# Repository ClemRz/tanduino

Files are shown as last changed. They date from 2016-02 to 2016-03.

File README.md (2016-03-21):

# Tanduino

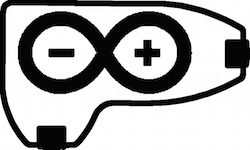
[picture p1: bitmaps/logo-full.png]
Tanduino


Tanduino is an Arduino based project aimed to mimic the analog "tandem" inclinometer + compass.

## User guide

* Power the device with a DC 3.3V to 9V battery.
* Turn on and off the device with the rocking switch.
* Push the temporary button to start the capturing procedure, you will hear a short chirp, hold the device as stable as possible. A second short chirp will be emitted once satisfactory values are read and the laser will go off. If you hear a long chirp push the temporary button again and try to hold the device more steadily.
* Maintain the temporary button pushed during more than 2s to enter in raw mode (for calibration purposes).
* When the laser diode is on don't look at it directly in the eye.
* The backlight level can be adjusted by rotating the 10KΩ trimmer resistor with a screwdriver.
* The laser power can be adjusted by rotating the 10Ω trimmer resistor with a screwdriver.

The compass is tilt compensated by the accelerometer.

The device must be recalibrated each time the hardware design is modified. Particularly if you decide to use a different battery format (4xAA instead of 1x9V for instance).

## Ratings

* Heading precision: ±0.1º
* Pitch precision: ±0.1º
* Power consumption*:
  - hold state: 41mW
  - unhold state: 149mW

*Measured with the lowest backlight level and a regular laser power at 20ºC.

## Developer guide

### Software design

#### Calibration

After any hardware change (PCB, enclosure, battery etc.), the magnetometer needs to be calibrated. This tutorial is a good start:

[Advanced hard and soft iron magnetometer calibration for dummies](http://diydrones.com/profiles/blogs/advanced-hard-and-soft-iron-magnetometer-calibration-for-dummies "Advanced hard and soft iron magnetometer calibration for dummies")

...

#### Dependencies

* [Adafruit Sensor library](https://github.com/adafruit/Adafruit_Sensor "Adafruit Sensor library")
* [Adafruit ADXL345 library](https://github.com/adafruit/Adafruit_ADXL345 "Adafruit ADXL345 library")
* [Adafruit HMC5883 Unified library](https://github.com/adafruit/Adafruit_HMC5883_Unified "Adafruit HMC5883 Unified library")
* [Adafruit GFX library](https://github.com/adafruit/Adafruit-GFX-Library "Adafruit GFX library")
* [Adafruit PCD8544 Nokia 5110 LCD library](https://github.com/adafruit/Adafruit-PCD8544-Nokia-5110-LCD-library "Adafruit PCD8544 Nokia 5110 LCD library")

### Electronic design

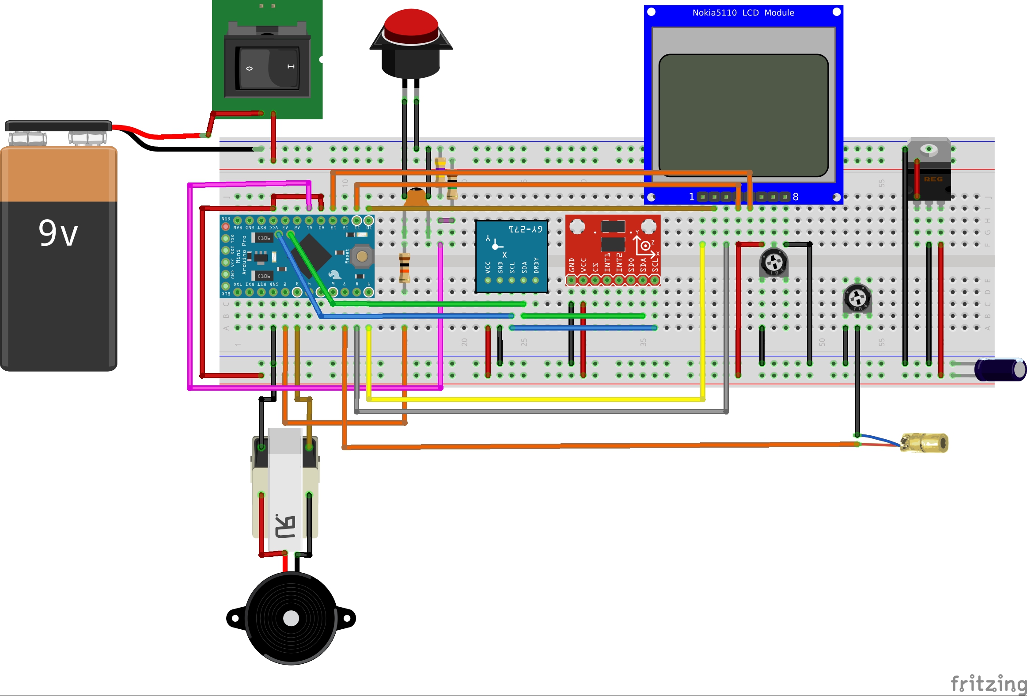
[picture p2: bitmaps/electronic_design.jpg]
Electronic design


#### Hardware list

* Arduino Pro Mini ATmega328 8MHz 3.3V
* Triple Axis Digital Compass HMC5883L
* Triple Axis Accelerometer ADXL345
* 84*48 LCD Display PCD8544
* 5mW 650nm 3V red laser diode
* Rocker on/off button
* Temporary push button
* 10kΩ resistor and 100nF ceramic capacitor for push button debouncing
* 470kΩ and 1MΩ resistors to divide battery voltage sensing
* 10kΩ trimmer resistor to adjust display's backlight
* 10Ω trimmer resistor to adjust laser power
* LT1521 3.3V 300mA voltage regulator and 1µF electrolitic capacitor
* Piezo flat speaker
* Autotransformer (boost piezo voltage)

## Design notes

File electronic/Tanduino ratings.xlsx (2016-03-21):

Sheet: Theorical power ratings
Tanduino operating current rating
Component | Theorical rating (mA)
Voltage regulator LT1521-3.3 | 0.012
Arduino Pro Mini 8MHz 3.3V | 3.58
Laser | 40
ADXL345 | 0.03
HMC5883L | 0.1
PCD8544 (w/t backlight) | 0.2
PCD8544 backlight | 6.8
Battery sensing | 0.006
Total | 50.728

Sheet: Experimental power ratings
Row Labels | Average of Power (mW)
boot | 47.32
hold | 40.51
measuring | 148.54
Grand Total | 122.04

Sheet: Data
running time (ms) | current (mA) | voltage (V) | Power (mW) | State
2619 | 74.7 | 8.46 | 631.96 | boot
2625 | 73.4 | 7.27 | 533.62 | boot
2632 | 11.6 | 7.33 | 85.03 | boot
2638 | 22.9 | 7.88 | 180.45 | boot
2647 | 11.2 | 8.22 | 92.06 | boot
2653 | 40 | 8.06 | 322.40 | boot
2660 | 10.8 | 8.21 | 88.67 | boot
2666 | 49 | 8.14 | 398.86 | boot
2673 | 4 | 8.31 | 33.24 | boot
2679 | 4 | 8.33 | 33.32 | boot
2686 | 6.6 | 8.33 | 54.98 | boot
2693 | 6.7 | 8.27 | 55.41 | boot
2700 | 6.7 | 8.26 | 55.34 | boot
2706 | 6.7 | 8.26 | 55.34 | boot
2713 | 6.9 | 8.26 | 56.99 | boot
2719 | 6.8 | 8.26 | 56.17 | boot
2726 | 6.9 | 8.26 | 56.99 | boot
2733 | 6.9 | 8.26 | 56.99 | boot
2740 | 6.9 | 8.25 | 56.93 | boot
2746 | 7.1 | 8.25 | 58.57 | boot
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

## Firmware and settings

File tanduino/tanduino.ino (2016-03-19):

/**
Copyright (c) 2016, Clément Ronzon
All rights reserved.

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
* Neither the name of tanduino nor the names of its
  contributors may be used to endorse or promote products derived from
  this software without specific prior written permission.

THIS SOFTWARE IS PROVIDED BY THE COPYRIGHT HOLDERS AND CONTRIBUTORS "AS IS"
AND ANY EXPRESS OR IMPLIED WARRANTIES, INCLUDING, BUT NOT LIMITED TO, THE
IMPLIED WARRANTIES OF MERCHANTABILITY AND FITNESS FOR A PARTICULAR PURPOSE ARE
DISCLAIMED. IN NO EVENT SHALL THE COPYRIGHT HOLDER OR CONTRIBUTORS BE LIABLE
FOR ANY DIRECT, INDIRECT, INCIDENTAL, SPECIAL, EXEMPLARY, OR CONSEQUENTIAL
DAMAGES (INCLUDING, BUT NOT LIMITED TO, PROCUREMENT OF SUBSTITUTE GOODS OR
SERVICES; LOSS OF USE, DATA, OR PROFITS; OR BUSINESS INTERRUPTION) HOWEVER
CAUSED AND ON ANY THEORY OF LIABILITY, WHETHER IN CONTRACT, STRICT LIABILITY,
OR TORT (INCLUDING NEGLIGENCE OR OTHERWISE) ARISING IN ANY WAY OUT OF THE USE
OF THIS SOFTWARE, EVEN IF ADVISED OF THE POSSIBILITY OF SUCH DAMAGE.
 */

#include <SPI.h>
#include <Wire.h>
#include <Adafruit_Sensor.h>
#include <Adafruit_ADXL345_U.h>
#include <Adafruit_HMC5883_U.h>
#include <Adafruit_GFX.h>
#include <Adafruit_PCD8544.h>
#include "structures.h"

// Debug options
#define VERBOSE_MODE                  0                       // Echo data to serial port: 0: none, 1 basic info, 2 detailed info, 3 extended info
#define WAIT_TO_START                 0                       // Wait for serial input in setup()

// General
#define MILLISEC                      1000L
#define SEC                           1L
#define MINUTE                        (unsigned int)60L*SEC
#define HOUR                          (unsigned int)60L*MINUTE
#define DAY                           (unsigned long)24L*HOUR

// Error codes
#define ERROR_ADXL345_INIT            1
#define ERROR_HMC5883_INIT            2
const char PROGMEM                                            //Remember to update the buffer when adding a larger string [7]
  errmsg_0[] =                        "",                     //SPARE
  errmsg_1[] =                        "Ac err",               //Accelerometer init error
  errmsg_2[] =                        "Co err";               //Compass init error
const char* const PROGMEM        
  ERROR_MESSAGES[] =                  {errmsg_0, errmsg_1, errmsg_2};

// Pins        
#define REFERENCE_3V3_PIN             A0                      // 3.3V reference for sampling
#define BATTERY_PIN                   A1                      // Battery sensing
#define BUTTON_PIN                    2                       // Interrupt pin
#define PIEZO_PIN                     3                       // Piezo speaker/buzzer pin
#define LASER_PIN                     7                       // Laser pointer
#define PCD8544_DC_PIN                8                       // LCD Data/Command select
#define PCD8544_RST_PIN               9                       // LCD Reset
#define PCD8544_CE_PIN                10                      // LCD Chip Select

// Sensors settings
#define ADXL345                       1                       // Accelerometer's ID
#define ADXL345_MEASURE               0x08                    // Value to put POWER_CTL register to measurement value
#define ADXL345_STANDBY               0x00                    // Value to put POWER_CTL register to standby value
#define HMC5883                       2                       // Compass's ID
#define HMC5883_MEASURE               0x00                    // Value to put MR register to continuous measurement value
#define HMC5883_IDLE                  0x02                    // Value to put MR register to idle value
#define READ_SAMPLES                  5.0                     // Number of samples to compute reading average
#define ALPHA                         0.7                     // Low Pass Filter constant
#define CAPTURING_SAMPLES             10                      // Number of samples for stabilization computation             
#define MAXIMUM_DEVIATION             0.2                     // Maximum deviation goal for data capturing (degrees)
#define STABILIZATION_TIMEOUT         2*SEC                   // Maximum allowed time to obtain a satisfactory deviation (seconds)

// Battery settings        
#define BATT_MIN                      7.0                     // Minimum voltage delivered by the battery (volts)
#define BATT_MAX                      9.0                     // Maximum voltage delivered by the battery (volts)
#define BATT_DIVIDER                  1.47/0.47               // Inverse ratio of the voltage divider that gives battery input ( (R1 + Rs) / Rs )
#define BATT_REFRESH_RATE             5*SEC                   // how often battery measurement is refreshed (seconds)

// Button settings        
#define DEBOUNCE_DELAY                50                      // Delay during which we ignore the button actions (milliseconds)
#define LONG_PUSH_DELAY               2*SEC                   // Delay to detect a long push versus a short push (seconds)

// Buzzer settings
#define FREQUENCY                     4100                    // Sound frequency (hertz)
#define SHORT_CHIRP                   50                      // Length of the short chirp (milliseconds)
#define LONG_CHIRP                    250                     // Length of the long chirp (milliseconds)

// Display settings        
#define PCD8544_CONTRAST              50                      // LCD Contrast value
#define PCD8544_SPI_CLOCK_DIV         SPI_CLOCK_DIV2          // Max SPI clock speed for PCD8544 of 2mhz (8mhz / 4)
#define PCD8544_REFRESH_RATE          0.175*SEC               // how often display is refreshed (seconds)
#define PCD8544_TEXT_WRAP             0                       // (true, false) wrap the text
#define PCD8544_FLIP                  1                       // (true, false) flip vertically the display

// Device settings
#define REVISION_NR                   F("1.0")                // Revision # of the design

// Calibration settings
#define BAUD                          9600                    // Serial communication baud for debug and calibration purposes
#define PITCH_0                       0.0942478               // Calibration pitch (rad) used to correct the offset between the horizontal plane and the sensors xy plane. Impact display only. Modify it as needed.
static const V
  _orientationADXL345 =               {-1, 1, 1},             // {x, y, z} Configuration vector to align the sensor output with the device coordinate system (NED: North, East, Down). Modify it as needed.
  _orientationHMC5883 =               {1, -1, -1},            // {x, y, z} Configuration vector to align the sensor output with the device coordinate system (NED: North, East, Down). Modify it as needed.
  _biasHMC5883 =                      {18.95, 7.244, 5.401};  // {x, y, z} Calibration vector used to correct the Hard Iron effect. Modify it as needed.
static const M
  _matrixHMC5883 =                    {1.442, -0.062, -0.053, // Calibration matrix used to correct the Soft Iron effect. Modify it as needed.
                                       -0.032, 1.497, 0.055,  // Theory arround calibration: http://www.nxp.com/files/sensors/doc/app_note/AN4246.pdf
                                       -0.117, 0.052, 1.554};

// Global variables
float
  _circularPitch[CAPTURING_SAMPLES],
  _circularHeading[CAPTURING_SAMPLES];
int _circularIndex =                  0;
Adafruit_PCD8544 _PCD8544 =           Adafruit_PCD8544(PCD8544_DC_PIN, PCD8544_CE_PIN, PCD8544_RST_PIN);
Adafruit_ADXL345_Unified _ADXL345 =   Adafruit_ADXL345_Unified(ADXL345);
Adafruit_HMC5883_Unified mag =        Adafruit_HMC5883_Unified(HMC5883);
static unsigned long
  _timer =                            -PCD8544_REFRESH_RATE*MILLISEC,
  _battTimer =                        -BATT_REFRESH_RATE*MILLISEC;
int _batt =                           0;
bool _calibrate =                     0,
     _hold =                          0,
     _standby =                       0,
     _serial =                        0,
     _circularLooped =                0,
     _beep =                          1;
S
  _yADXL345 =                         {0, 0, 0, 0, 0, 0, 0},
  _yHMC5883 =                         {0, 0, 0, 0, 0, 0, 0};
volatile unsigned long
  _v_lastInterruptTime =              0,
  _v_lowTime =                        0,
  _v_stabilizationTimer =             0;
volatile bool
  _v_toggle =                         0;
volatile uint8_t
  _v_buttonState =                    HIGH;

void setup(void) {
  initSerial();
  #if VERBOSE_MODE
  displaySketchInfo();
  #endif  //VERBOSE_MODE
  #if WAIT_TO_START
  Serial.println(F("Type any character to start"));
  while (!Serial.available());
  #endif //WAIT_TO_START
  initBuzzer();
  initButton();
  initBatt();
  initPCD8544();
  initADXL345();
  initHMC5883();
  initLaser();
}

void loop(void) {
  bool refresh = millis() - _timer > (unsigned long)PCD8544_REFRESH_RATE*MILLISEC;
  toogleSensors();
  if (!_hold && (_v_toggle || refresh)) buildSensorReadings();
  if (_v_toggle) toggleMeasurementMode();
  if(_v_buttonState == LOW && millis() - _v_lowTime > (unsigned long)LONG_PUSH_DELAY*MILLISEC) toggleCalibrationMode();
  if (millis() - _battTimer > (unsigned long)BATT_REFRESH_RATE*MILLISEC) refreshBattery();
  if (refresh) refreshDisplay();
}

void toogleSensors(void) {
  if (_standby != _hold) {
    if (_hold) {
      setADXL345ToStandbyMode();
      setHMC5883ToStandbyMode();
    } else {
      setADXL345ToMeasureMode();
      setHMC5883ToMeasureMode();
    }
    _standby = _hold;
  }
}

void buildSensorReadings(void) {
  if (!_yADXL345.failed) buildSensorReading(ADXL345);
  if (!_yHMC5883.failed) buildSensorReading(HMC5883);
}

void toggleMeasurementMode(void) {
  if (_beep || _hold) {
    shortChirp();
    _beep = false;
  }
  if (_hold) {
    _hold = false;
    _v_toggle = false;
    _beep = true;
  } else {
    consolidateCircularArrays();
    if (isStabilized()) {
      _hold = true;
      _v_toggle = false;
      shortChirp();
    } else if (millis() - _v_stabilizationTimer > (unsigned long)STABILIZATION_TIMEOUT*MILLISEC) {
      _v_toggle = false;
      longChirp();
    }
  }
}

void toggleCalibrationMode(void) {
  _v_buttonState = HIGH;
  _calibrate = !_calibrate;
  longChirp();
  initSerial();
}

void refreshBattery(void) {
  buildBatteryReading();
  _battTimer = millis();
}

void refreshDisplay(void) {
  printHMC5883();
  setLaserStatus();
  setPCD8544();
  _timer = millis();
}

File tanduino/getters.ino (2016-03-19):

/**
Copyright (c) 2016, Clément Ronzon
All rights reserved.

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
* Neither the name of tanduino nor the names of its
  contributors may be used to endorse or promote products derived from
  this software without specific prior written permission.

THIS SOFTWARE IS PROVIDED BY THE COPYRIGHT HOLDERS AND CONTRIBUTORS "AS IS"
AND ANY EXPRESS OR IMPLIED WARRANTIES, INCLUDING, BUT NOT LIMITED TO, THE
IMPLIED WARRANTIES OF MERCHANTABILITY AND FITNESS FOR A PARTICULAR PURPOSE ARE
DISCLAIMED. IN NO EVENT SHALL THE COPYRIGHT HOLDER OR CONTRIBUTORS BE LIABLE
FOR ANY DIRECT, INDIRECT, INCIDENTAL, SPECIAL, EXEMPLARY, OR CONSEQUENTIAL
DAMAGES (INCLUDING, BUT NOT LIMITED TO, PROCUREMENT OF SUBSTITUTE GOODS OR
SERVICES; LOSS OF USE, DATA, OR PROFITS; OR BUSINESS INTERRUPTION) HOWEVER
CAUSED AND ON ANY THEORY OF LIABILITY, WHETHER IN CONTRACT, STRICT LIABILITY,
OR TORT (INCLUDING NEGLIGENCE OR OTHERWISE) ARISING IN ANY WAY OUT OF THE USE
OF THIS SOFTWARE, EVEN IF ADVISED OF THE POSSIBILITY OF SUCH DAMAGE.
 */

S getADXL345(void) {
  sensors_event_t event; 
  _ADXL345.getEvent(&event);
  return getReadingFromSensor(event.acceleration);
}

S getHMC5883(void) {
  sensors_event_t event; 
  mag.getEvent(&event);
  return getReadingFromSensor(event.magnetic);
}

void buildSensorReading(int sensorId) {
  buildAverageAndFilteredReading(sensorId);
  switch (sensorId) {
    case ADXL345:
      _yADXL345.roll = getRoll(_yADXL345.y, _yADXL345.z);
      _yADXL345.pitch = getPitch(_yADXL345.x, _yADXL345.y, _yADXL345.z, _yADXL345.roll);
      break;
    case HMC5883:
      _yHMC5883.heading = getHeading(_yHMC5883.x, _yHMC5883.y, _yHMC5883.z, _yADXL345.roll, _yADXL345.pitch);
      break;
  }
}

void buildBatteryReading(void) {
  _batt = getBatteryLevel();
}

void buildAverageAndFilteredReading(int sensorId) {
  S sensor = getAverage(sensorId);
  switch (sensorId) {
    case ADXL345:
      calibarteADXL345(&sensor);
      lowPassFilter(&sensor, &_yADXL345);
      break;
    case HMC5883:
      calibarteHMC5883(&sensor);
      lowPassFilter(&sensor, &_yHMC5883);
      break;
  }
}

S getAverage(int sensorId) {
  S sensor = {0, 0, 0, 0, 0, 0, 0};
  for(int i=0; i<READ_SAMPLES; i++) {
    sum2Sensors(&sensor, getSensor(sensorId));
    delay(5);
  }
  divideSensor(&sensor, READ_SAMPLES);
  return sensor;
}

S getSensor(int sensorId) {
  S sensor;
  switch (sensorId) {
    case ADXL345:
      sensor = getADXL345();
      break;
    case HMC5883:
      sensor = getHMC5883();
      break;
  }
  return sensor;
}

S getReadingFromSensor(sensors_vec_t sensor) {
  S reading = {0, 0, 0, 0, 0, 0, 0};
  for(int i=0; i<3; i++) reading.floatAt[i] = sensor.v[i];
  return reading;
}

// Inspired from https://github.com/adafruit/Adafruit_AHRS/blob/master/Adafruit_Simple_AHRS.cpp
// and http://cache.freescale.com/files/sensors/doc/app_note/AN4248.pdf
float getPitch(float x, float y, float z, float roll) {  
  float pitch, d = y * sin(roll) + z * cos(roll);
  if (d == 0) {
    pitch =  x > 0 ? (-M_PI / 2) : (M_PI / 2);
  } else {
    pitch = (float)atan(-x / d);
  }
  if (pitch > M_PI / 2) pitch = M_PI - pitch;
  if (pitch < -M_PI / 2) pitch = -M_PI - pitch;
  return pitch;
}

// Inspired from http://cache.freescale.com/files/sensors/doc/app_note/AN4248.pdf
float getRoll(float y, float z) {
  return atan2(y, z);
}

float getHeading(float x, float y, float z, float roll, float pitch) {
  if (_yADXL345.failed) return getNotTiltCompensatedHeading(x, y);
  return getTiltCompensatedHeading(x, y, z, roll, pitch);
}

float getTiltCompensatedHeading(float x, float y, float z, float roll, float pitch) {
  float sinRoll = sin(roll),
        cosRoll = cos(roll),
        cosPitch = cos(pitch),
        nz = y * sinRoll + z * cosRoll;
  if (cosPitch < 0) cosPitch *= -1;
  return atan2(z * sinRoll - y * cosRoll, x * cosPitch + nz * sin(pitch));
}

float getNotTiltCompensatedHeading(float x, float y) {
  return atan2(y, x);
}

char *getError(char* a, uint8_t errorCode) {
  char *ret = a;
  strcpy_P(ret, (char*)pgm_read_word(&(ERROR_MESSAGES[errorCode])));
  #if VERBOSE_MODE
  Serial.print(F("error #"));
  Serial.print(errorCode);
  Serial.print(F(": "));
  Serial.println(ret);
  #endif  //VERBOSE_MODE
  return ret;
}

int getBatteryLevel(void) {
  return round(mapD(getBatteryVoltage(), BATT_MIN, BATT_MAX, 0.0, 4.0));
}

float getBatteryVoltage(void) {
  return getOutputVoltage(BATTERY_PIN)*BATT_DIVIDER;
}

float getOutputVoltage(int pinToRead) {
  return averageAnalogRead(pinToRead) * 3.3 / averageAnalogRead(REFERENCE_3V3_PIN); // volts
}

bool isStabilized(void) {
  if (!_circularLooped) return false;
  if (stddev(_circularPitch, CAPTURING_SAMPLES) >= MAXIMUM_DEVIATION) return false;
  if (stddev(_circularHeading, CAPTURING_SAMPLES) >= MAXIMUM_DEVIATION) return false;
  _yADXL345.pitch = mean(_circularPitch, CAPTURING_SAMPLES);
  _yHMC5883.heading = mean(_circularHeading, CAPTURING_SAMPLES);
  return true;
}

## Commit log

2016-01-28 Filters signal. Stable version.
2016-02-05 Adds degree sign. Monitors battery level.
2016-02-07 Fixes many bugs. Stable.
    [getters.ino, icons.ino, initialisers.ino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]
2016-02-08 Adds degree sign. Flashes icon when battery is empty.
2016-02-12 Adds buzzer, laser and button. Stable. WIP.
    [initialisers.ino, interrupts.ino, setters.ino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]
2016-02-12 Adds degree symbol. Removes buzzer and interrupts (not so usefull). Stable.
    [icons.ino, initialisers.ino, interrupts.ino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]
2016-02-12 Adds electronic design.
    [tanduino.fzz]
2016-02-13 Adds a hard debouncer to the button.
    [tanduino.fzz]
2016-02-14 Fixes the LCD contrast issue. Renames some vars. Takes into account the voltage divider for the battery level sensing.
    [getters.ino, initialisers.ino, tanduino.ino]
2016-02-15 Updates electronic design.
    [tanduino.fzz]
2016-02-15 Updates documentation.
    [Tanduino ratings.xlsx]
2016-03-01 Fixes tilt compensation and adds alignment and hard/soft iron correction vectors.
    [debugger.ino, getters.ino, initialisers.ino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]
2016-03-01 Adds first prototype pics.
2016-03-01 Adds pitch calibration constant.
2016-03-03 Optimises calibration. Adds Soft Iron calibration logic.
2016-03-04 Fixes tilt compensation formulas and calibration vectors and matrix.
    [getters.ino, tanduino.ino, utils.ino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]
2016-03-04 Activates calibration matrix.
2016-03-07 Adds calibration display on long push.
2016-03-08 Fixes calibration display
2016-03-09 Adds buzzer.
    [tanduino.fzz]
2016-03-10 Adds power management.
2016-03-11 Updates the configuration corresponding to packaging. Calibrates the pitch.
2016-03-11 Adds Serial communication on calibration mode.
2016-03-12 Calibrates the magnetometer.
2016-03-19 Adds a 2 steps capture method to minimize noise and prevent push-button vibrations to distort the signal.
    [getters.ino, initialisers.ino, interrupts.ino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]
2016-03-19 Updates power ratings.
    [Tanduino ratings.xlsx]
2016-03-21 Adds more pictures of the prototype.
